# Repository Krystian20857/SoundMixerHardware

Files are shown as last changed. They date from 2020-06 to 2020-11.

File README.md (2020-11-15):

# SoundMixerHardware
SoundMixerHardware is sub-repository of [Sound Mixer](https://github.com/Krystian20857/SoundMixer) project. This repository contains:
* Electric schematics
* PCB desings
* BOM files 
* GERBER files
* STL models to print.

This repo might contains multiple versions of hardware. Each hardware configuration is located in separated folder. To learn more about each version read README.md in specified folder.

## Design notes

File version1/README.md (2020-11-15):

Schematic and PCB have been created using EasyEDA software which is integrated with LCSC part supplier. Using these tools speed up design process and made it easier.

[Easyeda Link](https://easyeda.com/krystian2004/soundmixerhardware)

## Content
* [Description](#sound-mixer-hardware)
* [Electric Design](#electric-design)
* [Models](#models)

## Electric Design
Design is very simple it consists of microcoltroller, power providers, sliders, buttons and connectors. I predict alternative usage of linear voltage stabilizer and SMPS for more power hungry systems. Remember not to solder these parts together. All of microcoltroller pins are drived to external gold-pins.

#### Schematic
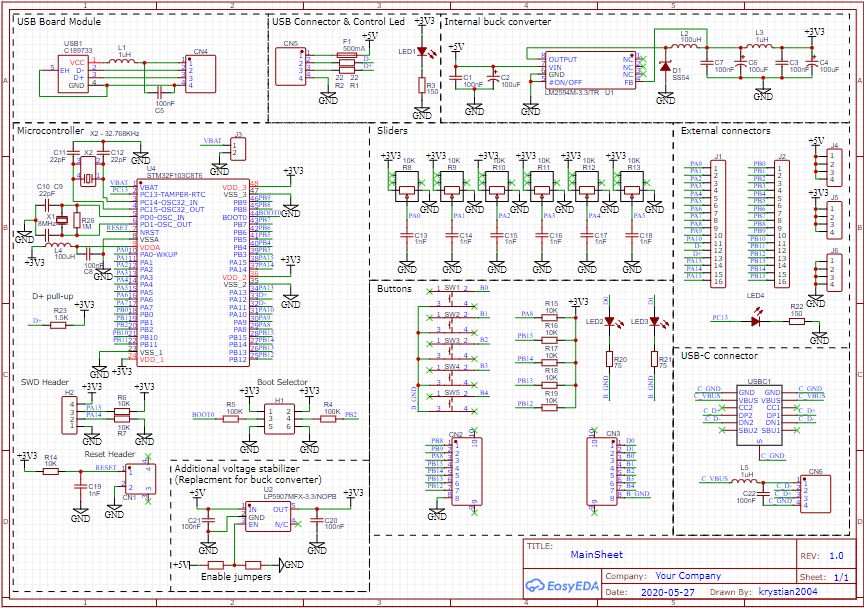
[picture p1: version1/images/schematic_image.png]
Schematic


PCB consists of 4 separated PCBs: 
* USB-C connector
* USB-A connector
* Buttons Board
* Main Board

#### PCB Top
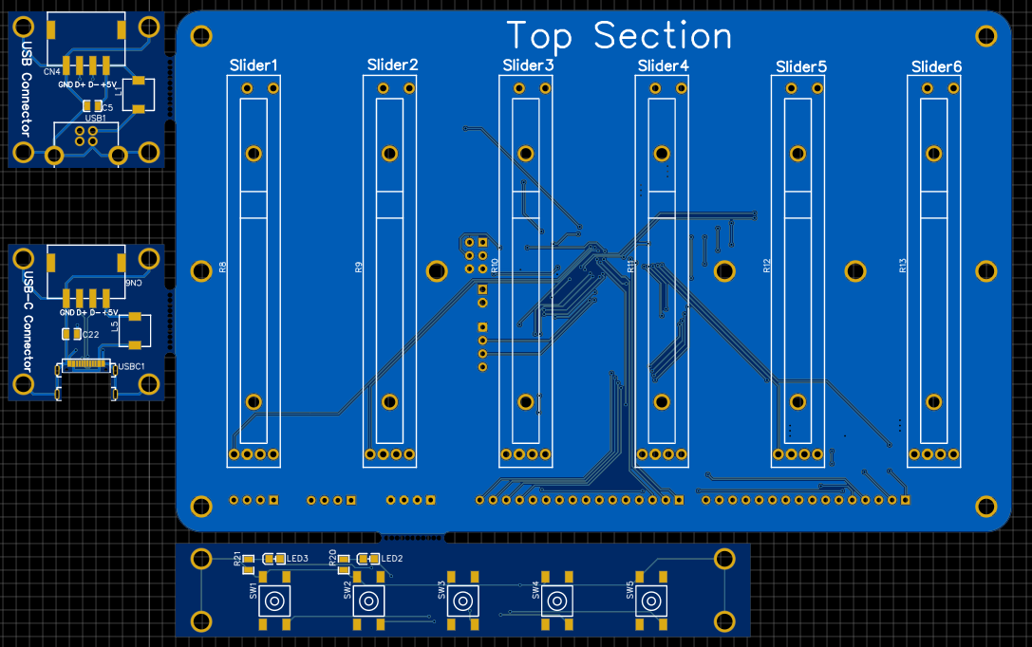
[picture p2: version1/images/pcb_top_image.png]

#### PCB Bottom
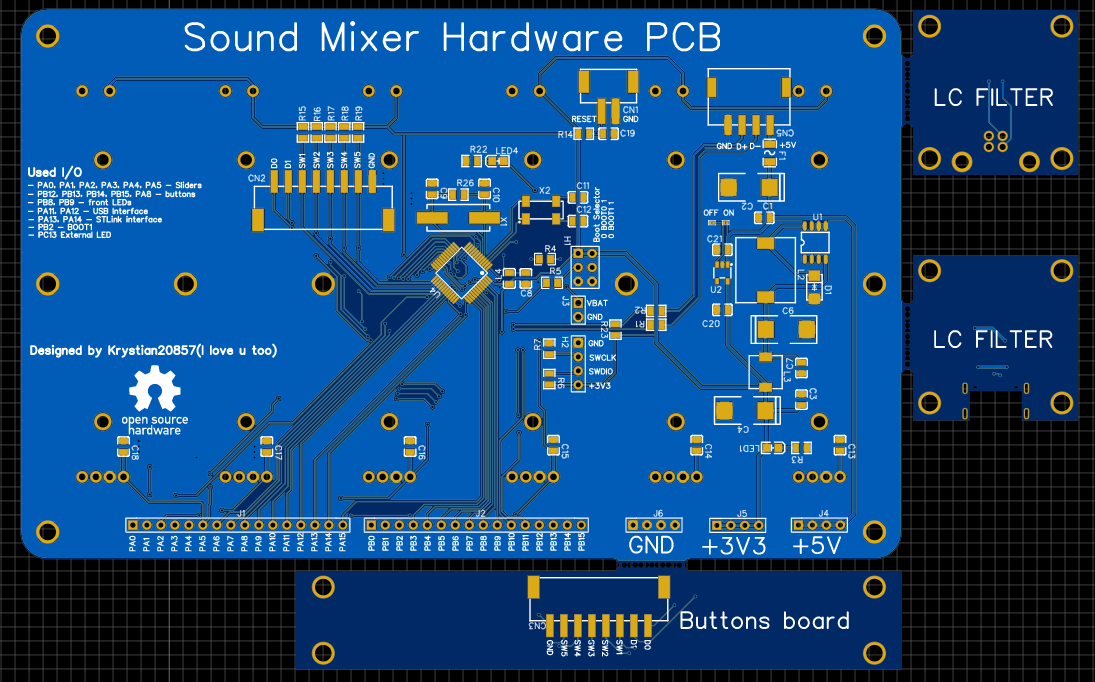
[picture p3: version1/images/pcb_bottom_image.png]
PCB bottom

#### PCB Top in real life
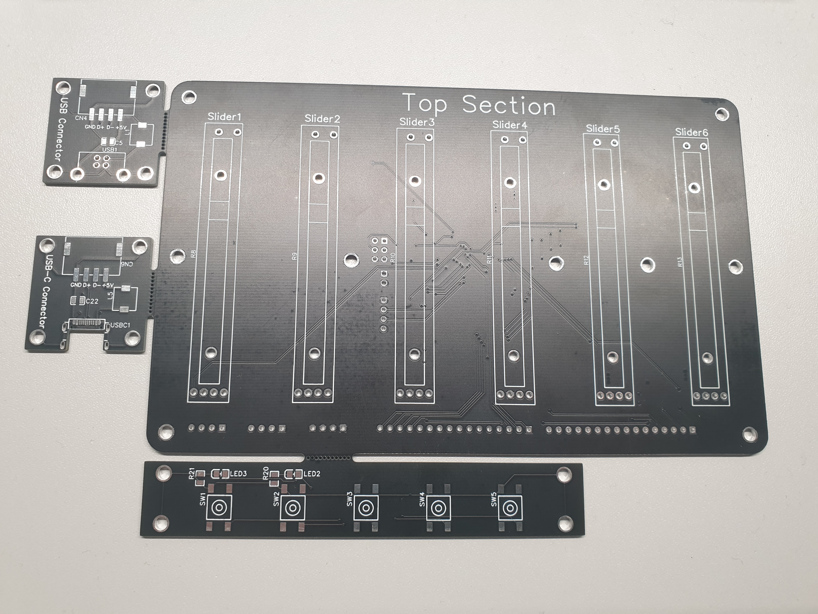
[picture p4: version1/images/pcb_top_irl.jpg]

#### PCB Bottom in real life
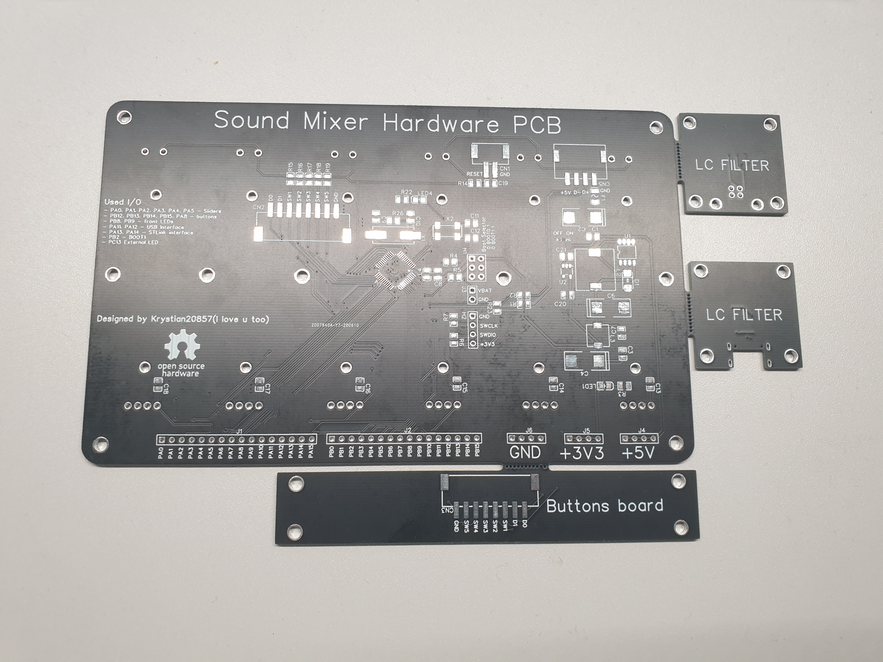
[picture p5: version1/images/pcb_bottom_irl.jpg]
PCB bottom


## Models
Models have been designed in *Fusion 360* and printed using *Anycubic i3 mega 3D printer* and *Anet A6 3D printer* with help of CURA slicing software.
#### Top Conver Model
Print Settings:
* Layer Height: 0.2mm
* Infill: 25%
* Supports: Yes
* Adhesion: None

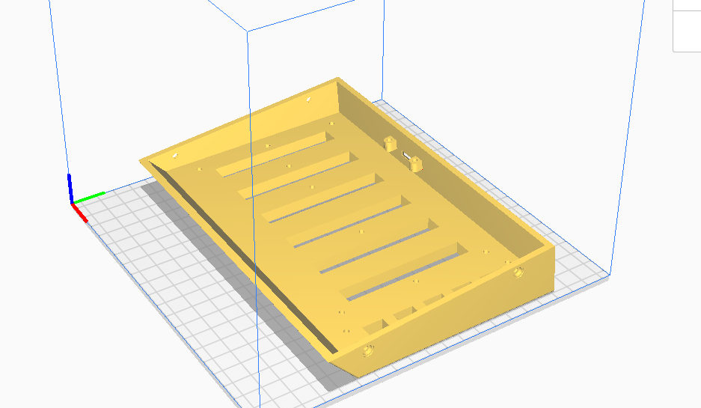
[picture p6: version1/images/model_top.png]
Top Cover Model


#### Bottom Conver Model
Print Settings:
* Layer Height: 0.2mm
* Infill: 30%
* Supports: None
* Adhesion: None

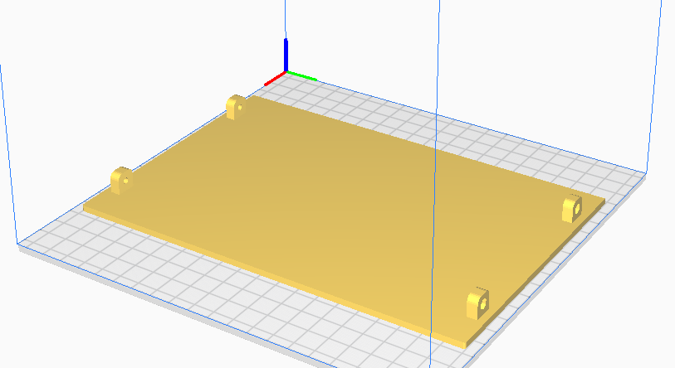
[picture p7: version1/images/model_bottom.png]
Bottom Cover Model


#### Other Models
Print Settings:
* Layer Height: 0.2mm
* Infill: 50%
* Supports: None
* Adhesion: Brim

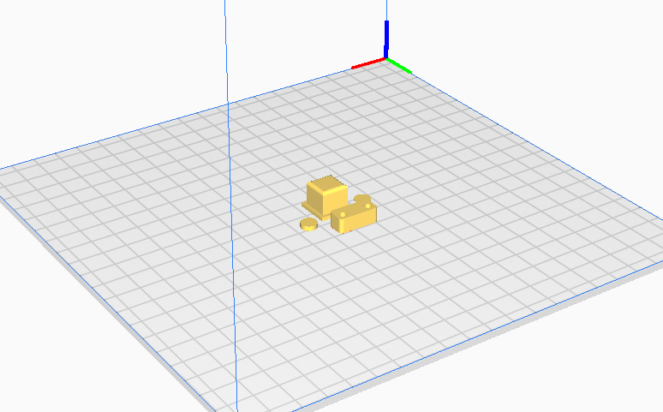
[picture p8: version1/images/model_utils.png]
Other Models


## End Result
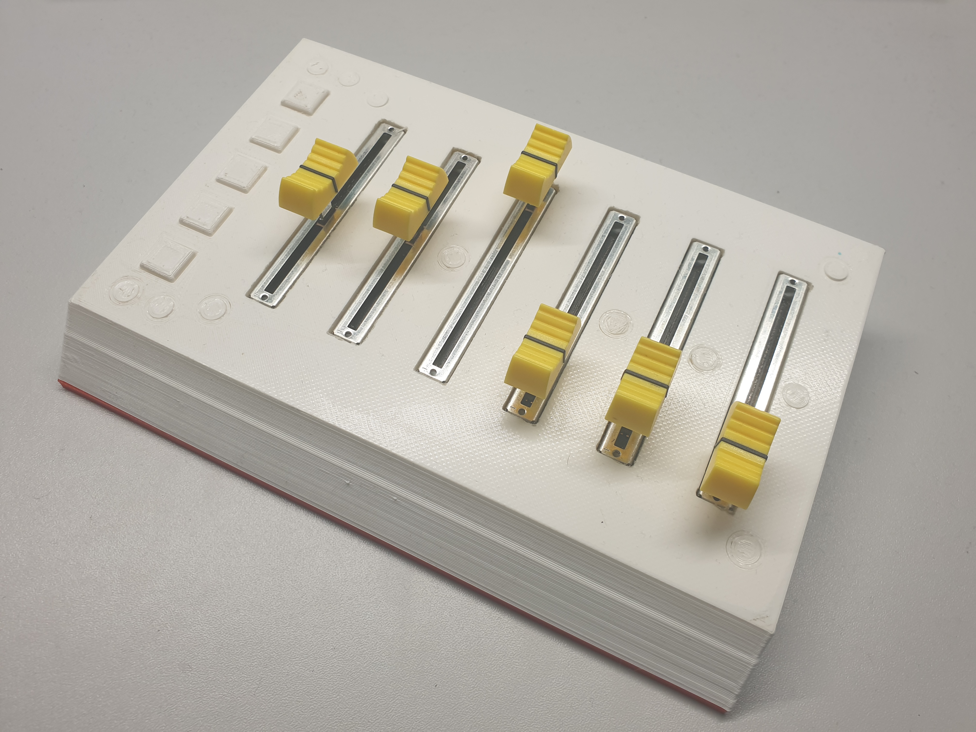
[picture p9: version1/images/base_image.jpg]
Sound Mixer

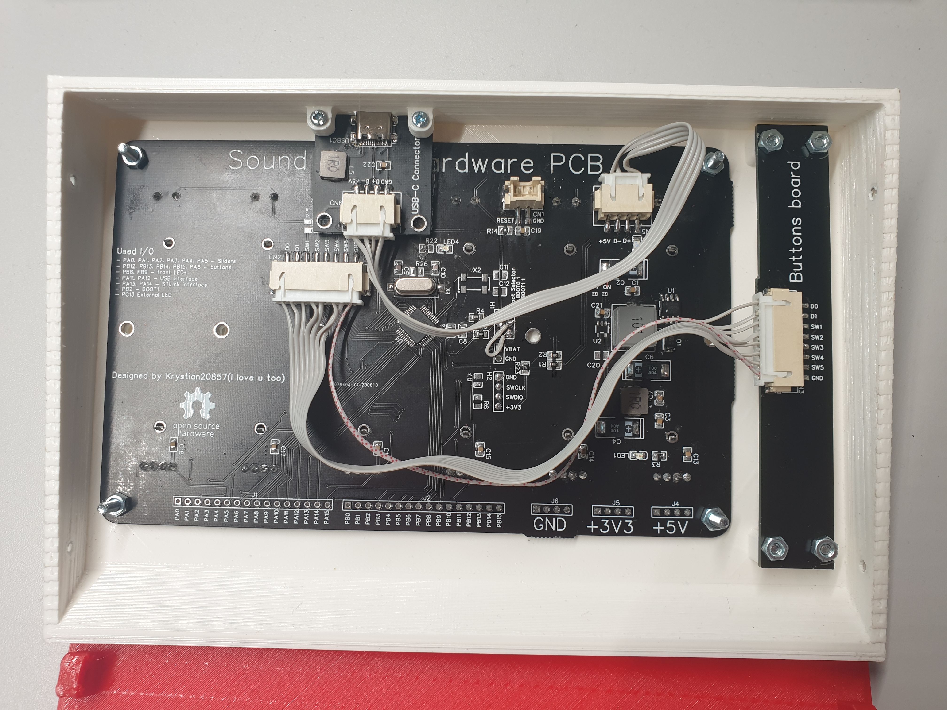
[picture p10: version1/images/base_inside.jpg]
Sound Mixer Inside


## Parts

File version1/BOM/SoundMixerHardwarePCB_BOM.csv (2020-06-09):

ID | Name | Designator | Footprint | Quantity | Manufacturer Part | Manufacturer | Supplier | Supplier Part | LCSC Assembly
1 | 22pF | C10,C9,C11,C12 | C0805 | 4 | CL21C220JBANNNC | SAMSUNG | LCSC | C1804 | Yes
2 | 1TS005F-2500-5001 | SW2,SW1,SW5,SW3,SW4 | KEY-SMD_4P-L6.0-W6.0-P4.50 | 5 | 1TS005F-2500-5001 | HYP | LCSC | C255812
3 | 2.54-4P | CN4,CN5,CN6 | CONN-SMD_2.54-4P-WT | 3 | - | Boom Precision Elec | LCSC | C146120
4 | 75 | R20,R21 | R0805 | 2 | 0805W8J0750T5E | UniOhm | LCSC | C25327
5 | 2.54-8P | CN2,CN3 | CONN-SMD_2.54-8P-WT | 2 | - | Boom Precision Elec | LCSC | C146124
6 | TYPE-C-31-M-14 | USBC1 | USB-C-SMD_12P-P0.50-H-F_TYPE-C-31-M-14 | 1 | TYPE-C-31-M-14 | Rectangular Connectors - Contacts | LCSC | C223907
7 | XH2.54-2AB | CN1 | CONN-SMD_2P-P2.54_XH2.54-2AB | 1 | - | Boom Precision Elec | LCSC | C146125
8 | LP5907MFX-3.3/NOPB | U2 | SOT-23-5_L3.0-W1.7-P0.95-LS2.8-BL | 1 | LP5907MFX-3.3/NOPB | Texas Instruments | LCSC | C80670 | Yes
9 | 100uF | C4,C2,C6 | CAP-SMD_L7.3-W4.3 | 3 | 10TPC100M | PANASONIC | LCSC | C147766 | Yes
10 | 1uH | L1,L3,L5 | IND-SMD_L6.0-W6.0_SLF6028T | 3 | SLO0618H1R0MTT | Sunltech Tech | LCSC | C216188
11 | 100uH | L2 | IND-SMD_L11.8-W10.8 | 1 | JSHC1040H-101M-G | Jinlai | LCSC | C334110
12 | SS54 | D1 | SMA_L4.4-W2.8-LS5.4-R-RD | 1 | SS54 | MDD | LCSC | C22452 | Yes
13 | HDR-M-2.54_1x16 | J2,J1 | HDR-M-2.54_1X16 | 2 |  |  | LCSC | C50981
14 | 8MHz | X1 | OSC-SMD_L11.5-W4.8-P9.50 | 1 | X49SM8MSD2SC | YXC | LCSC | C12674
15 | 500mA | F1 | F1206 | 1 | - | XC Elec(Shenzhen) | LCSC | C140466
16 | 22 | R1,R2 | R0805 | 2 | TC0525F220JT5E | UniOhm | LCSC | C65068 | Yes
17 | 100uH | L4 | L0805 | 1 | MLF2012C101KT000 | TDK | LCSC | C68035 | Yes
18 | 100K | R4,R5 | 805 | 2 | 080500F1003T5E | UniOhm | LCSC | C149504
19 | 17-21SURC/S530-A3/TR8 | LED3,LED4,LED2,LED1 | LED0805-R-RD | 4 | 17-21SURC/S530-A3/TR8 | EVERLIGHT | LCSC | C72037 | Yes
20 | STM32F103C8T6 | U4 | LQFP-48_L7.0-W7.0-P0.50-LS9.0-BL | 1 | STM32F103C8T6 | STMicroelectronics | LCSC | C8734 | Yes
21 | 10K | R13,R8,R9,R10,R11,R12 | RES-ADJ-TH_RS6011SP6003 | 6 | RS6011SP6003 | ALPS Electric | LCSC | C370993
22 | HDR-M-2.54_1x2 | J3 | HDR-M-2.54_1X2 | 1 |  |  | LCSC | C124375
23 | X2 - 32.768KHz | X2 | MC-306_4P-L8.0-W3.2-P5.5-BL | 1 | Q13MC3061000300 | EPSON | LCSC | C16320 | Yes
24 | C189733 | USB1 | USB-B_TH_BF90 | 1 | C189733 | Shenzhen Cankemeng | LCSC | C189733
25 | 100nF | C8,C7,C5,C1,C21,C20,C22,C3 | C0805 | 8 | CL21B104KBCNNNC | SAMSUNG | LCSC | C1711
26 | 1M | R26 | R0805 | 1 | 0805W8J0105T5E | UniOhm | LCSC | C26115
27 | LM2594M-3.3/TR | U1 | SOP-8_L5.0-W4.0-P1.27-LS6.0-BL | 1 | LM2594M-3.3/TR | HGSEMI | LCSC | C316691 | Yes
28 | HDR-F-2.54_2x3 | H1 | HDR-F-2.54_2X3 | 1 |  |  | LCSC | C65114
29 | HDR-F-2.54_1x4 | H2 | HDR-F-2.54_1X4 | 1 |  |  | LCSC | C225501
30 | 10K | R16,R17,R18,R19,R7,R6,R14,R15 | R0805 | 8 | 0805W8J0103T5E | UniOhm | LCSC | C25612
31 | 150 | R22,R3 | R0805 | 2 | 0805W8J0151T5E | UniOhm | LCSC | C25283
32 | HDR-M-2.54_1x4 | J6,J5,J4 | HDR-M-2.54_1X4 | 3 |  |  | LCSC | C124378
33 | 1k | R25,R24 | R0201 | 2
34 | 1.5K | R23 | R0805 | 1 | 0805W8J0152T5E | UniOhm | LCSC | C26015
35 | 1nF | C14,C13,C19,C18,C17,C16,C15 | C0805 | 7 | CL21B102KCANNNC | SAMSUNG | LCSC | C15177 | Yes

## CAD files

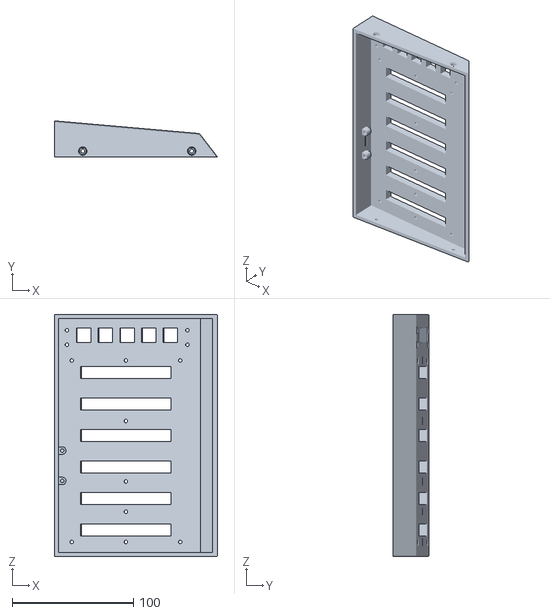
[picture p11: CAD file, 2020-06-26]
version1/Models/TopCover.stl
135.0 x 30.0 x 200.0

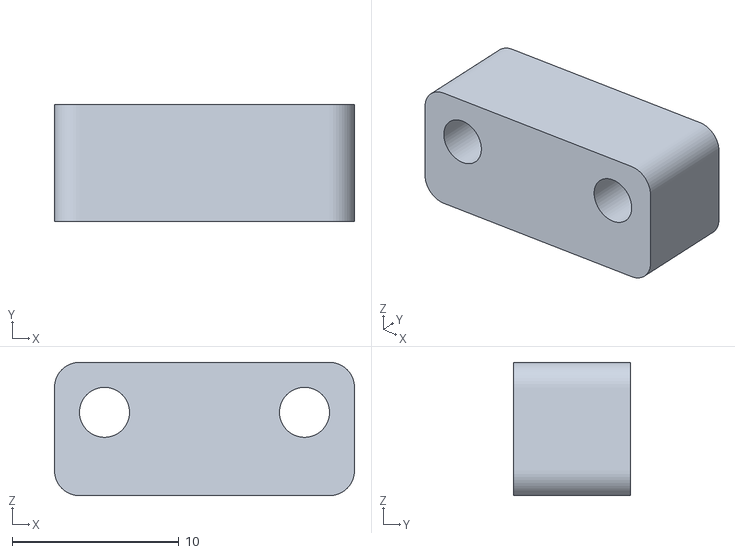
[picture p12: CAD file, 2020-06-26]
version1/Models/ButtonsPCBSpacing.stl
18.0 x 7.00 x 8.00

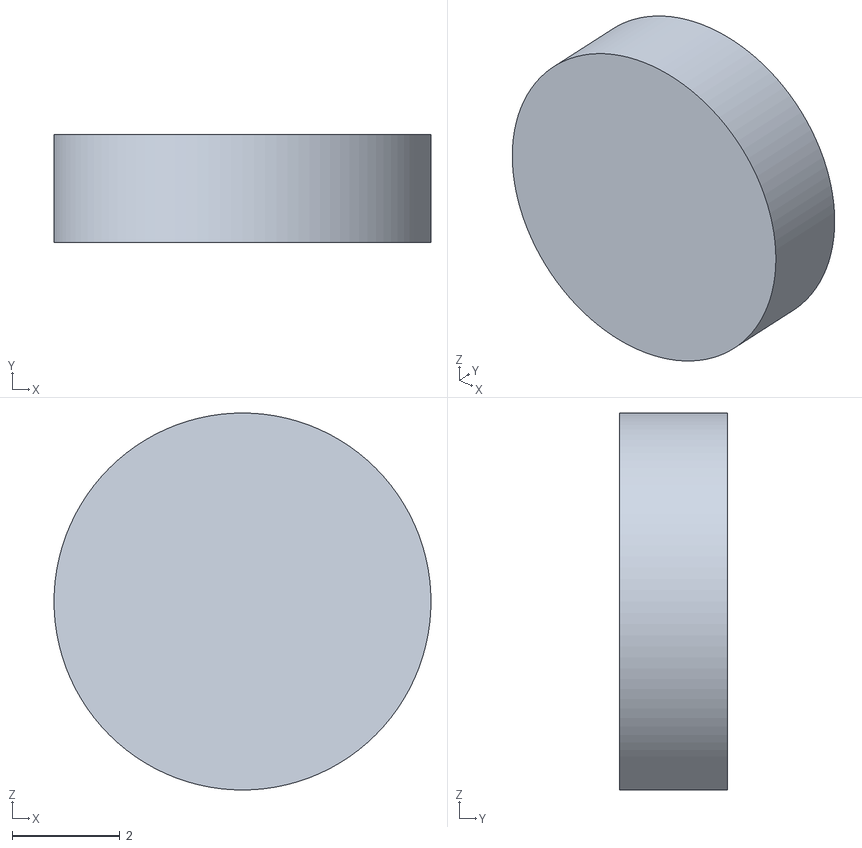
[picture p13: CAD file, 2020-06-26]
version1/Models/2mmCap.stl
7.00 x 2.00 x 7.00

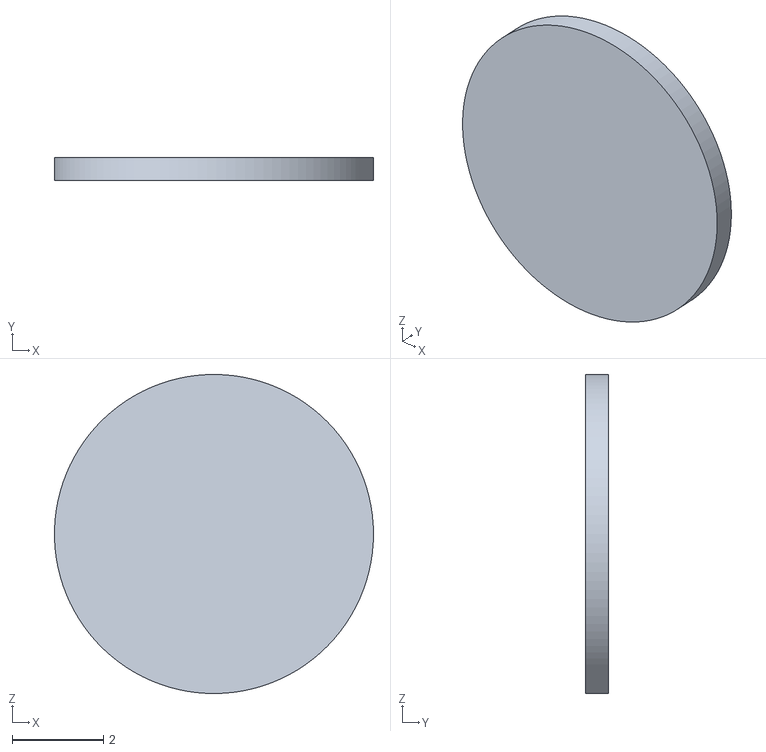
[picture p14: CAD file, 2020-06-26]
version1/Models/0.5mmCap.stl
7.00 x 0.5 x 7.00

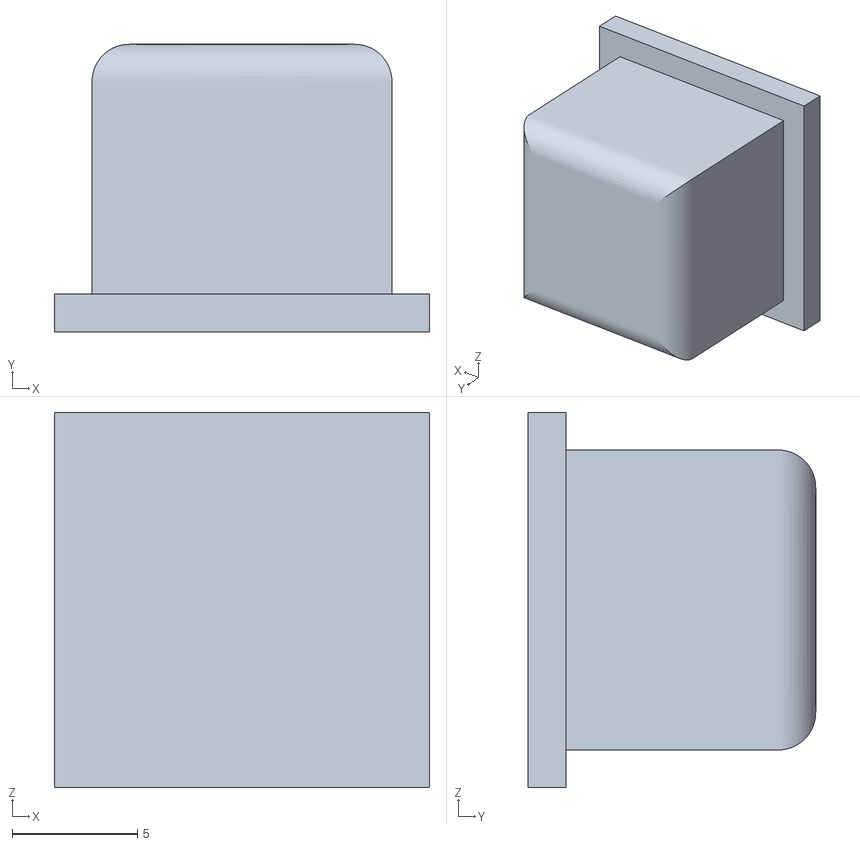
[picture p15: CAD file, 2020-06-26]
version1/Models/DefaultButton.stl
15.0 x 11.5 x 15.0

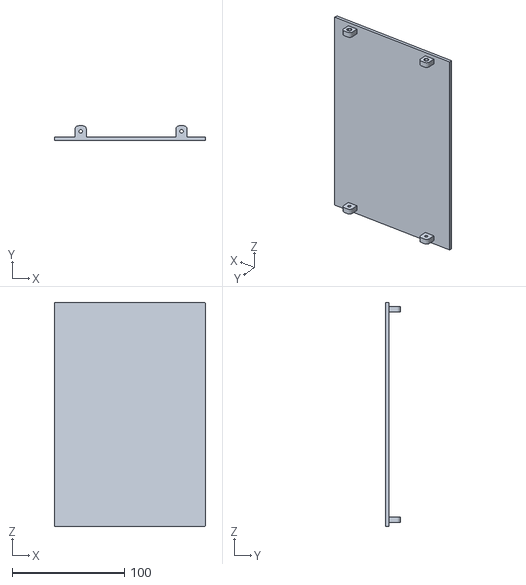
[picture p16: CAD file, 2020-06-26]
version1/Models/BottomCover.stl
135.0 x 13.0 x 200.0

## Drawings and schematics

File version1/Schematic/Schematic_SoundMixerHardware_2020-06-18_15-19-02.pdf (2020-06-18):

USB Board Module | USB Connector & Control Led | Internal buck converter

## Microcontroller

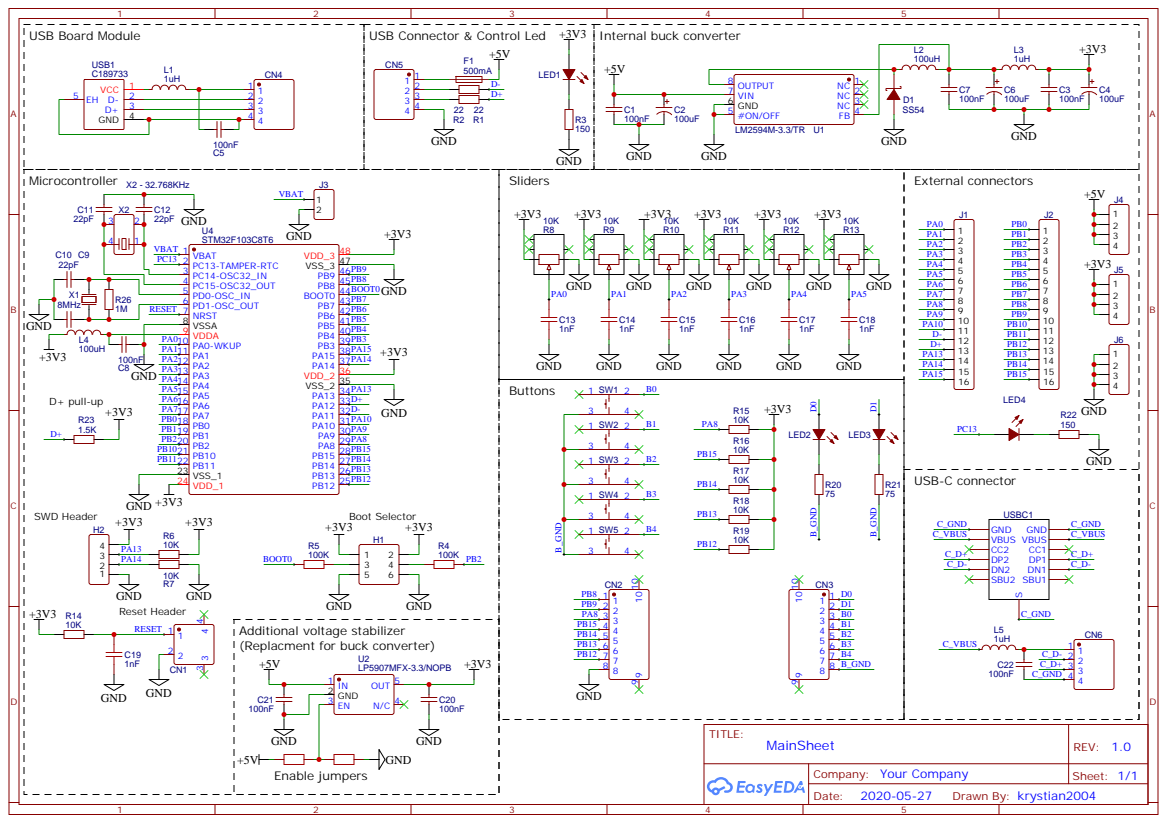
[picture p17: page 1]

Additional voltage stabilizer
(Replacment for buck converter)

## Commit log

2020-06-09 Initial commit, pcb gerbers and bom file.
    [SoundMixerHardwarePCB_BOM.csv]
2020-06-18 Added schematic & fixed main board usb connector label
2020-06-26 Added new models
    [0.5mmCap.stl, 2mmCap.stl, BottomCover.stl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]
2020-08-03 Added schematic and pcb images.
2020-08-03 Added pcb images irl.
2020-11-15 Updated repo structure.
    [0.5mmCap.stl, 2mmCap.stl, BottomCover.stl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]
